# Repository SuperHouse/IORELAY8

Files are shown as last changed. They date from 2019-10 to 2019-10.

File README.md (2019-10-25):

I/O Breakout To 8 Relay Drivers
===============================
Copyright 2017-2019 SuperHouse Pty Ltd  
SuperHouse site:  www.superhouse.tv  

Breaks out a 2x6 pin header to 8 low-side MOSFETs suitable for switching
loads such as relays.

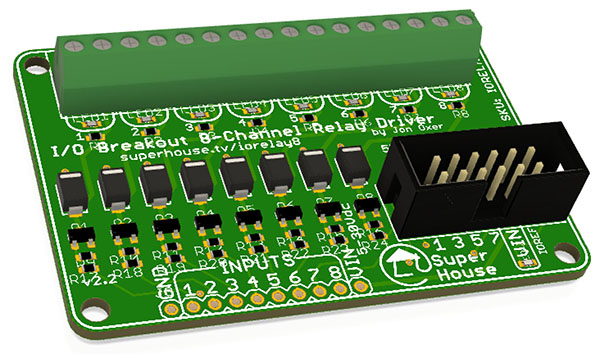
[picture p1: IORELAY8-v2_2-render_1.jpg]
PCB render


Features:

 * Inputs from both a 2x6 shrouded header and separate solder pads

More information is available at:

  http://www.superhouse.tv/iorelay8

INSTALLATION
------------
The design is saved as an EAGLE project. EAGLE PCB design software is
available from www.cadsoftusa.com free for non-commercial use. To use
this project download it and place the directory containing these files
into the "eagle" directory on your computer. Then open EAGLE and
navigate to the project.

DISTRIBUTION
------------
The specific terms of distribution of this project are governed by the
license referenced below.

LICENSE
-------
Licensed under the TAPR Open Hardware License (www.tapr.org/OHL).
The "license" folder within this repository also contains a copy of
this license in plain text format.

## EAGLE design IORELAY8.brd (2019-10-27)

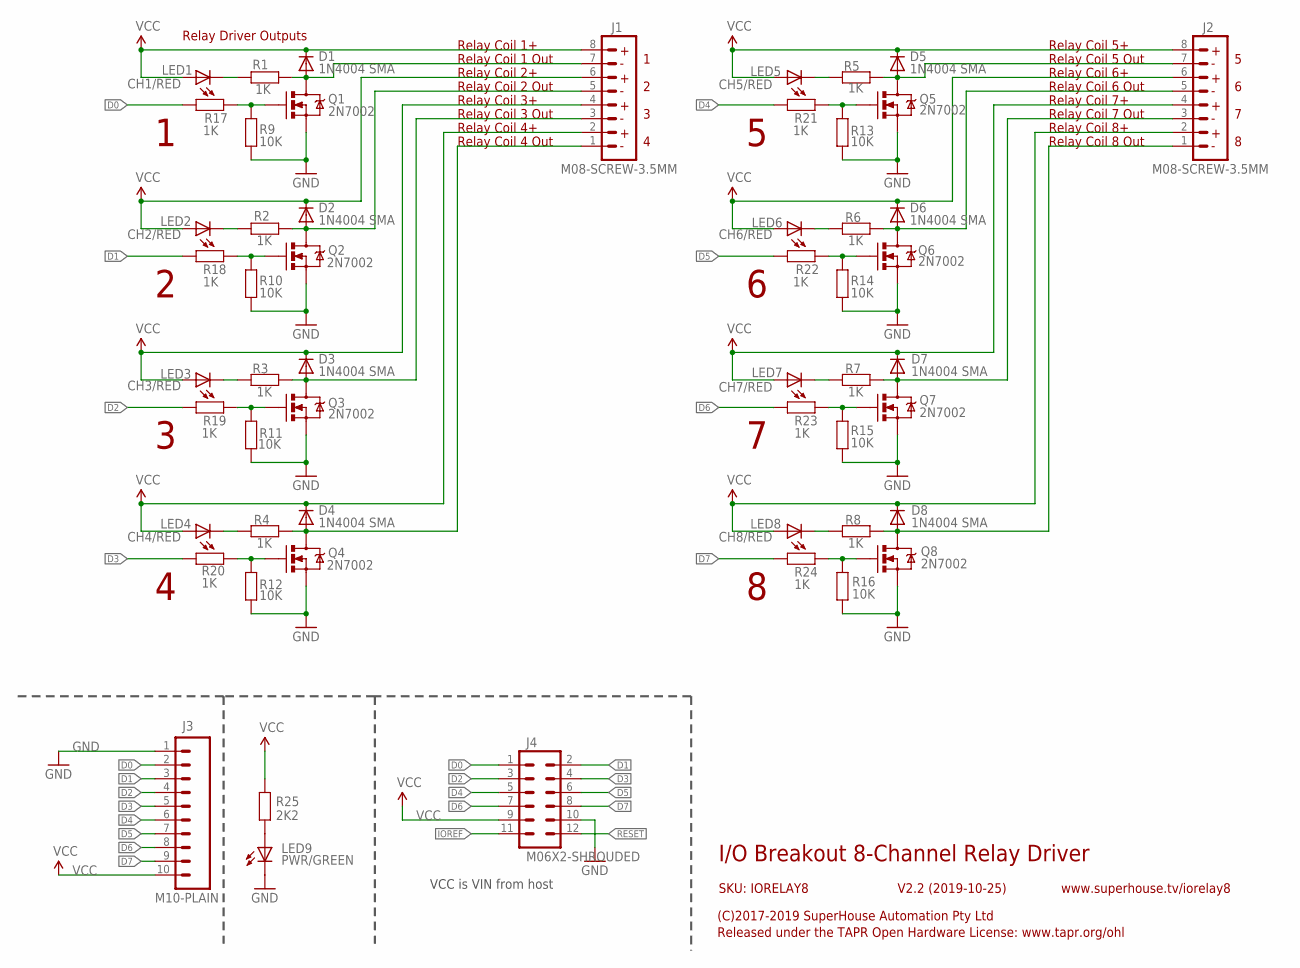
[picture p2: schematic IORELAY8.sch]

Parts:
D1, D2, D3, D4, D5, D6, D7, D8: 1N4004 SMA; SMA-DIODE
J1, J2: M08-SCREW-3.5MM; SCREWTERMINAL_3.5MM_8
J3: M10-PLAIN; 1X10
J4: M06X2-SHROUDED; 2X6-SHROUDED
LED1: CH1/RED; LED-0603
LED2: CH2/RED; LED-0603
LED3: CH3/RED; LED-0603
LED4: CH4/RED; LED-0603
LED5: CH5/RED; LED-0603
LED6: CH6/RED; LED-0603
LED7: CH7/RED; LED-0603
LED8: CH8/RED; LED-0603
LED9: PWR/GREEN; LED-0603
Q1, Q2, Q3, Q4, Q5, Q6, Q7, Q8: 2N7002; SOT23-3
R1, R2, R3, R4, R5, R6, R7, R8, R17, R18, R19, R20, R21, R22, R23, R24: 1K; R0603
R9, R10, R11, R12, R13, R14, R15, R16: 10K; R0603
R25: 2K2; R0603

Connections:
D0: J3.2, J4.1, R17.2
D1: J3.3, J4.2, R18.2
D2: J3.4, J4.3, R19.2
D3: J3.5, J4.4, R20.2
D4: J3.6, J4.5, R21.2
D5: J3.7, J4.6, R22.2
D6: J3.8, J4.7, R23.2
D7: J3.9, J4.8, R24.2
GND: J3.1, J4.10, LED9.C, Q1.2 (S), Q2.2 (S), Q3.2 (S), Q4.2 (S), Q5.2 (S), Q6.2 (S), Q7.2 (S), Q8.2 (S), R9.1, R10.1, R11.1, R12.1, R13.1, R14.1, R15.1, R16.1
IOREF: J4.11
unnamed: Q1.1 (G), R9.2, R17.1
unnamed: D2.A, J1.5, Q2.3 (D), R2.2
unnamed: LED9.A, R25.1
unnamed: D1.A, J1.7, Q1.3 (D), R1.2
unnamed: Q2.1 (G), R10.2, R18.1
unnamed: D3.A, J1.3, Q3.3 (D), R3.2
unnamed: Q3.1 (G), R11.2, R19.1
unnamed: D4.A, J1.1, Q4.3 (D), R4.2
unnamed: Q4.1 (G), R12.2, R20.1
unnamed: D5.A, J2.7, Q5.3 (D), R5.2
unnamed: Q5.1 (G), R13.2, R21.1
unnamed: D6.A, J2.5, Q6.3 (D), R6.2
unnamed: Q6.1 (G), R14.2, R22.1
unnamed: D7.A, J2.3, Q7.3 (D), R7.2
unnamed: Q7.1 (G), R15.2, R23.1
unnamed: D8.A, J2.1, Q8.3 (D), R8.2
unnamed: Q8.1 (G), R16.2, R24.1
unnamed: LED2.C, R2.1
unnamed: LED4.C, R4.1
unnamed: LED3.C, R3.1
unnamed: LED1.C, R1.1
unnamed: LED5.C, R5.1
unnamed: LED6.C, R6.1
unnamed: LED7.C, R7.1
unnamed: LED8.C, R8.1
RESET: J4.12
VCC: D1.C, D2.C, D3.C, D4.C, D5.C, D6.C, D7.C, D8.C, J1.2, J1.4, J1.6, J1.8, J2.2, J2.4, J2.6, J2.8, J3.10, J4.9, LED1.A, LED2.A, LED3.A, LED4.A, LED5.A, LED6.A, LED7.A, LED8.A, R25.2

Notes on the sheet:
I/O Breakout 8-Channel Relay Driver
V2.2 (2019-10-25)
SKU: IORELAY8
(C)2017-2019 SuperHouse Automation Pty Ltd
Released under the TAPR Open Hardware License: www.tapr.org/ohl
www.superhouse.tv/iorelay8
Relay Coil 1 Out
Relay Coil 1+
Relay Coil 2+
Relay Coil 3+
Relay Coil 4+
Relay Coil 4 Out
Relay Coil 3 Out
Relay Coil 2 Out
Relay Coil 8 Out
Relay Coil 8+
Relay Coil 5+
Relay Coil 5 Out
Relay Coil 6+
Relay Coil 6 Out
Relay Coil 7+
Relay Coil 7 Out
Relay Driver Outputs
VCC is VIN from host

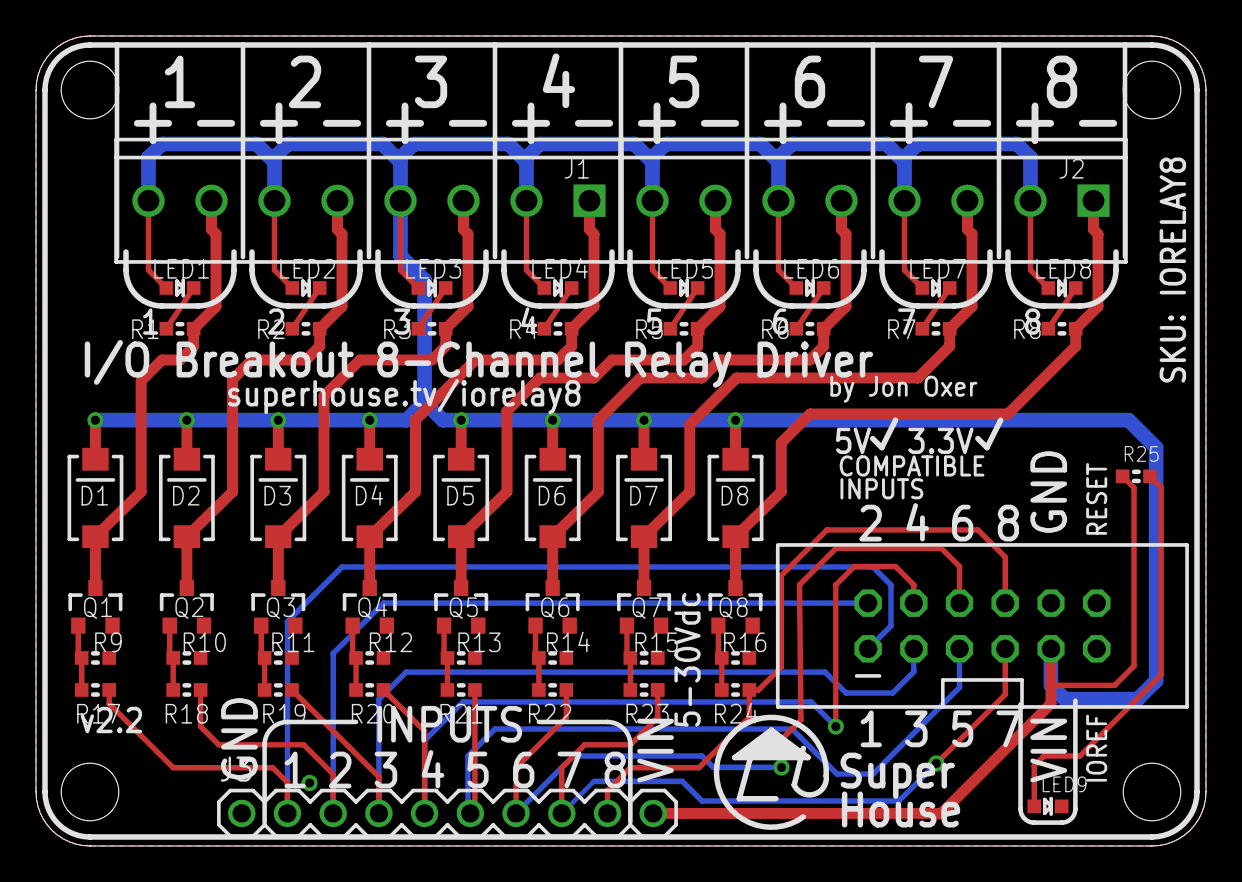
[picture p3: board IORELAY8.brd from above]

Board: 2 copper layers, 65.0 x 45.0 mm, 55 parts (1 on the bottom side), 35 nets.

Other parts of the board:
U$6: OSHW_10X200_NOTEXT

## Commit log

2017-07-21 Initial project import for possible v1.0 release
    [IOR8.brd, IOR8.sch]
2017-07-24 Expanded headers to 2x6 to include IOREF and RESET for v2.0 release
    [IOR8.brd, IOR8.sch]
2017-07-24 Renamed project files
    [IORELAY8.brd, IORELAY8.sch]
2017-07-25 Resized board on metric grid
    [IORELAY8.brd, IORELAY8.sch]
2017-08-03 Improved position of part designators
    [IORELAY8.brd]
2019-07-01 Replaced most parts using SuperHouse library to add 3D models
    [IORELAY8.brd, IORELAY8.sch]
2019-07-18 Replaced parts using SuperHouse libraries to add 3D models
    [IORELAY8.brd, IORELAY8.sch]
2019-10-25 Silkscreen change for v2.2 release
    [IORELAY8.brd, IORELAY8.sch]
2019-10-27 DRC, designator, and value cleanups for v2.2 release
    [IORELAY8.brd, IORELAY8.sch]

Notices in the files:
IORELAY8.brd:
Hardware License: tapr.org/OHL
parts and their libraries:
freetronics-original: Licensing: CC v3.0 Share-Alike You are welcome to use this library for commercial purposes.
